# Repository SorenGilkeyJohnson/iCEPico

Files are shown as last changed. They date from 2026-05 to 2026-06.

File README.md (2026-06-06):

# iCEPico

> A compact development board combining the **RP2350** microcontroller and the **ICE40UP5K-SG48I** FPGA in a Raspberry Pi Pico form factor.

---

## Overview

The iCEPico is a custom PCB that pairs the RP2350 with the Lattice ICE40UP5K-SG48I FPGA. The board is modelled after the Raspberry Pi Pico, with the addition of the FPGA and a +1V2 regulator to supply it. The board matches the physical dimensions of the Pico, though it does **not** replicate the Pico's pinout.

I made this project because I wanted to learn FPGA design. Initially, I thought about using a BGA package but decided to go with QFN instead due to PCB costs and complexity. I had previously designed for the RP2040 but never the RP2350. I plan to use the project as a general-purpose dev board, a learning tool for FPGAs for me, and to teach students at my school's robotics club.

---
[Here is KiCanvas!](https://kicanvas.org/?repo=https%3A%2F%2Fgithub.com%2FSorenGilkeyJohnson%2FiCEPico%2Ftree%2Fmain%2FKiCad)

## Board Images

<table>
  <tr>
    <td align="center"><strong>Top View</strong></td>
    <td align="center"><strong>Bottom View</strong></td>
  </tr>
  <tr>
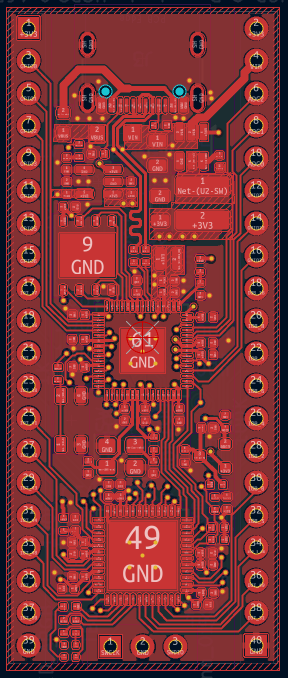
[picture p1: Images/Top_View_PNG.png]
Top View
    <td></td>
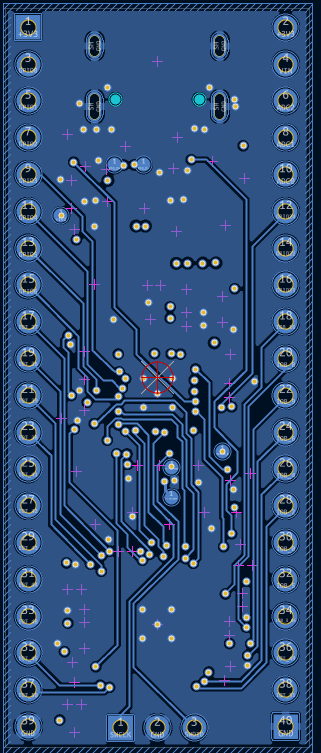
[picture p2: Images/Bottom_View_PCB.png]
Bottom View
    <td></td>
  </tr>
  <tr>
    <td align="center"><strong>3D Top</strong></td>
    <td align="center"><strong>3D Bottom</strong></td>
  </tr>
  <tr>
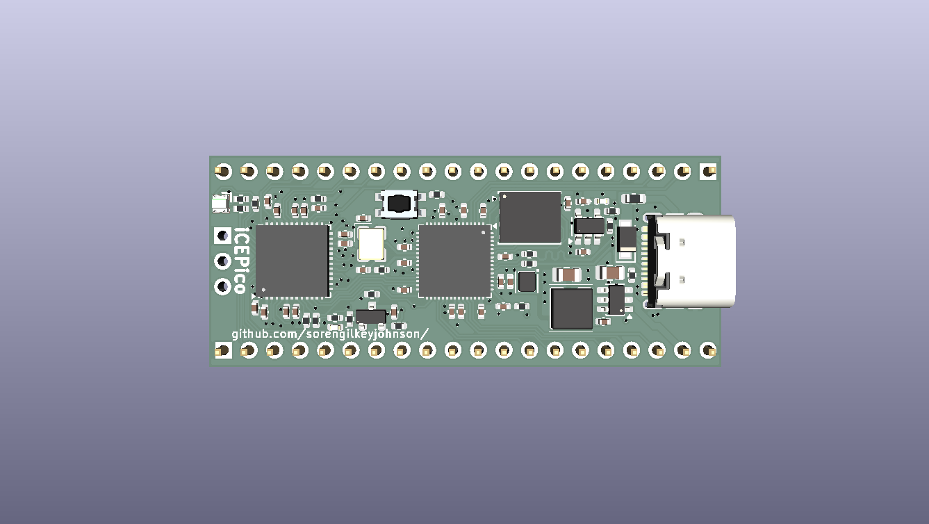
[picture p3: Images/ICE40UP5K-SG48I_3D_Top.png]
3D Top
    <td></td>
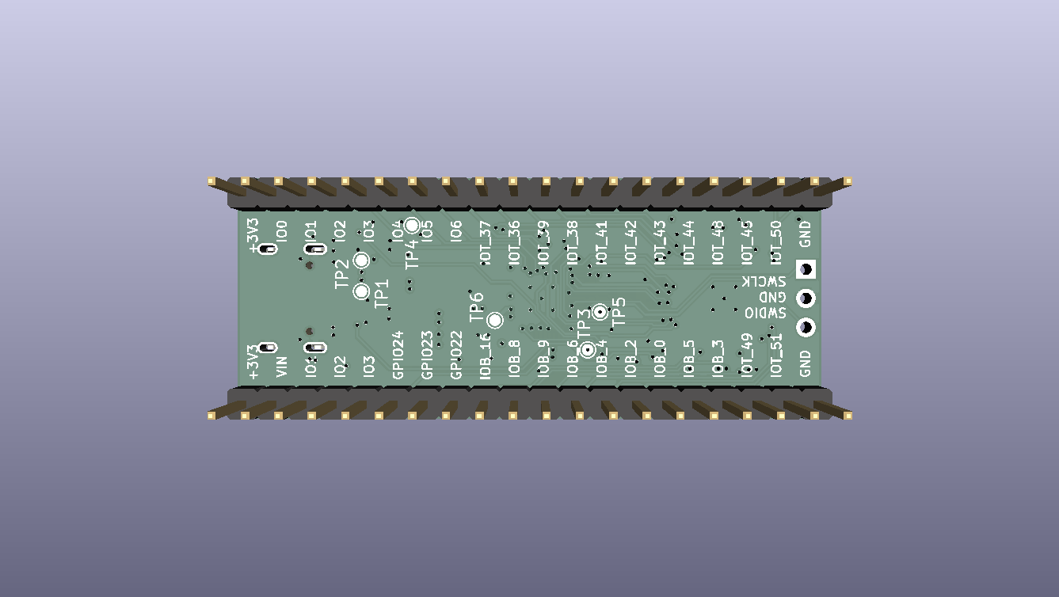
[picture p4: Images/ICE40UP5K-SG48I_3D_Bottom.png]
3D Bottom
    <td></td>
  </tr>
</table>

 [View Schematic (PDF)](Images/ICE40UP5K-SG48I_Schematic.pdf)

---

## Hardware

| Component | Part |
|---|---|
| Microcontroller | RP2350 |
| FPGA | Lattice ICE40UP5K-SG48I |
| QSPI Flash | W25Q128JVP |
| 3.3V Regulator | AP63203 (Buck) |
| 1.2V Regulator | TLV75612PDBV (LDO) |

### RP2350 <-> FPGA Interconnect

The FPGA flash is the RP2350 via bit-banging. The two chips share **8 GPIO lines** aligned to the RP2350's HSTX peripheral.

### PCB Stack-Up

| Layer | Function |
|---|---|
| 1 | Signal / Components |
| 2 | GND |
| 3 | PWR (primarily 3V3) |
| 4 | Signal |

---

## Power

The board can be powered via:
- **USB-C**      : 5V VBUS through a Schottky diode
- **VIN header** : direct voltage input

---

## Programming

| Method | Target | Description |
|---|---|---|
| USB (UF2) | RP2350 | Drag-and-drop bootloader over USB-C |
| SWD | RP2350 | Debug header for OpenOCD / probe-rs |
| Bit-bang (via RP2350) | ICE40 FPGA | FPGA bitstream loaded by the RP2350 firmware |

---

## Pinout

| Pin | Left Signal | | Right Signal | Pin |
|-----|---|---|---|-----|
| 1  | GND | | +3V3 | 2  |
| 3  | GPIO0 | | +VIN | 4  |
| 5  | GPIO1 | | ADC2 | 6  |
| 7  | GPIO2 | | ADC1 | 8  |
| 9  | GPIO3 | | ADC0 | 10 |
| 11 | GPIO4 | | GPIO24 | 12 |
| 13 | GPIO5 | | GPIO23 | 14 |
| 15 | GPIO6 | | GPIO22 | 16 |
| 17 | IOT_37 | | IOB_16 | 18 |
| 19 | IOT_36 | | IOB_8 | 20 |
| 21 | IOT_39 | | IOB_9 | 22 |
| 23 | IOT_38 | | IOB_6 | 24 |
| 25 | IOT_41 | | IOB_4 | 26 |
| 27 | IOT_42 | | IOB_2 | 28 |
| 29 | IOT_43 | | IOB_0 | 30 |
| 31 | IOT_44 | | IOB_5 | 32 |
| 33 | IOT_48 | | IOB_3 | 34 |
| 35 | GND | | GND | 36 |
| 37 | IOT_45 | | IOT_49 | 38 |
| 39 | IOT_50 | | IOT_51 | 40 |

---

## Repository Structure

```
iCEPico/
├── Images/                          # Board renders and schematic export
│   ├── Bottom_View_PCB.png
│   ├── ICE40UP5K-SG48I_3D_Bottom.png
│   ├── ICE40UP5K-SG48I_3D_Top.png
│   ├── ICE40UP5K-SG48I_Schematic.pdf
│   └── Top_View_PNG.png
├── KiCad/                           # KiCad project files
│   ├── ICE40UP5K-SG48I.kicad_pcb
│   ├── ICE40UP5K-SG48I.kicad_prl
│   ├── ICE40UP5K-SG48I.kicad_pro
│   └── ICE40UP5K-SG48I.kicad_sch
├── fabrication/                     # Fabrication outputs
│   ├── bom.csv
│   ├── gerbers.zip
│   └── pick_and_place.csv
├── hardware/                        # Hardware source files
│   ├── ICE40UP5K-SG48I.kicad_pcb
│   ├── ICE40UP5K-SG48I.kicad_pro
│   └── ICE40UP5K-SG48I.kicad_sch
├── LICENSE
└── README.md
```

---

## License

See [LICENSE](LICENSE) for details.

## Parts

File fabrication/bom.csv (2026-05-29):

Index | LCSC# | MPN | Manufacturer | Package | Customer # | Description | RoHS | Quantity | MOQ | Multiple | Unit Price($) | Extended Price($) | Product Link
1 | C52895 | BSS138 | onsemi | SOT-23 |  | N-Channel 50V 0.22A 0.36W Surface Mount SOT-23 | yes | 10 | 10 | 10 | 0.0680 | 0.68 | https://www.lcsc.com/product-detail/C52895.html
2 | C20625731 | ABM8-272-T3 | ABRACON | SMD3225-4P |  | ±30ppm 10pF ±30ppm SMD3225-4P Crystals RoHS | yes | 5 | 5 | 5 | 0.2947 | 1.47 | https://www.lcsc.com/product-detail/C20625731.html
3 | C42411118 | RP2350A | Raspberry Pi | QFN-60-EP(7x7) |  | QFN-60-EP(7x7) Microcontrollers RoHS | yes | 1 | 1 | 1 | 1.1886 | 3.57 | https://www.lcsc.com/product-detail/C42411118.html
4 | C2441427 | W25Q128JVPIM TR | Winbond | WSON-8-EP(5x6) |  | FLASH - NOR Memory IC 128Mbit SPI 133MHz WSON-8-EP(5x6) | yes | 1 | 1 | 1 | 3.0644 | 9.19 | https://www.lcsc.com/product-detail/C2441427.html
5 | C2877864 | TLV75512PDBVR | TI | SOT-23-5 |  | Linear Voltage Regulator IC Positive Fixed 1 Output 500mA SOT-23-5 | yes | 5 | 5 | 5 | 0.1722 | 0.86 | https://www.lcsc.com/product-detail/C2877864.html
6 | C780769 | AP63203WU-7 | DIODES | TSOT-23-6 |  | 1.1MHz Step-down type Fixed 2A 3.3V 3.8V~32V TSOT-23-6 Voltage Regulators - DC DC Switching Regulators RoHS | yes | 3 | 1 | 1 | 0.5463 | 1.64 | https://www.lcsc.com/product-detail/C780769.html
7 | C2678152 | ICE40UP5K-SG48I | Lattice | QFN-48-EP(7x7) |  | 5280 660 QFN-48-EP(7x7) FPGAs (Field Programmable Gate Array) RoHS | yes | 1 | 1 | 1 | 8.0688 | 24.21 | https://www.lcsc.com/product-detail/C2678152.html
8 | C138002 | RC0402FR-0733RL | YAGEO | 0402 |  | 62.5mW 33Ω 50V Thick Film Resistor ±100ppm/℃ ±1% 0402 Chip Resistor - Surface Mount RoHS | yes | 100 | 100 | 100 | 0.0009 | 0.09 | https://www.lcsc.com/product-detail/C138002.html
9 | C2909343 | FRC0402F27R0TS | FOJAN | 0402 |  | 27Ω ±1% 62.5mW 0402 Thick Film Resistor | yes | 100 | 100 | 100 | 0.0007 | 0.07 | https://www.lcsc.com/product-detail/C2909343.html
10 | C106235 | RC0402FR-071KL | YAGEO | 0402 |  | 1kΩ 62.5mW 50V Thick Film Resistor ±100ppm/℃ ±1% 0402 Chip Resistor - Surface Mount RoHS | yes | 100 | 100 | 100 | 0.0009 | 0.09 | https://www.lcsc.com/product-detail/C106235.html
11 | C60491 | RC0402FR-07100KL | YAGEO | 0402 |  | 100kΩ 62.5mW 50V Thick Film Resistor ±100ppm/℃ ±1% 0402 Chip Resistor - Surface Mount RoHS | yes | 100 | 100 | 100 | 0.0009 | 0.09 | https://www.lcsc.com/product-detail/C60491.html
12 | C60490 | RC0402FR-0710KL | YAGEO | 0402 |  | 62.5mW 10kΩ 50V Thick Film Resistor ±100ppm/℃ ±1% 0402 Chip Resistor - Surface Mount RoHS | yes | 100 | 100 | 100 | 0.0009 | 0.09 | https://www.lcsc.com/product-detail/C60490.html
13 | C106232 | RC0402FR-07100RL | YAGEO | 0402 |  | 100Ω 62.5mW 50V Thick Film Resistor ±100ppm/℃ ±1% 0402 Chip Resistor - Surface Mount RoHS | yes | 100 | 100 | 100 | 0.0008 | 0.08 | https://www.lcsc.com/product-detail/C106232.html
14 | C105872 | RC0402FR-075K1L | YAGEO | 0402 |  | 5.1kΩ 62.5mW 50V Thick Film Resistor ±100ppm/℃ ±1% 0402 Chip Resistor - Surface Mount RoHS | yes | 100 | 100 | 100 | 0.0009 | 0.09 | https://www.lcsc.com/product-detail/C105872.html
15 | C131394 | CC0402KRX7R9BB104 | YAGEO | 0402 |  | 100nF ±10% 50V Ceramic Capacitor X7R 0402 | yes | 100 | 100 | 100 | 0.0037 | 0.37 | https://www.lcsc.com/product-detail/C131394.html
16 | C42411119 | AOTA-B201610S3R3-101-T | ABRACON | 0806 |  | 2.1A 3.3uH 115mΩ 2.4A Molded Inductor 0806 Fixed Inductors RoHS | yes | 5 | 5 | 5 | 0.2843 | 1.42 | https://www.lcsc.com/product-detail/C42411119.html
17 | C6808101 | ANR4030T3R9M | APV | SMD,4x4mm |  | 2.3A 3.9uH ±20% 3.3A Magnetic Shielded Inductor SMD,4x4mm Fixed Inductors RoHS | yes | 10 | 10 | 10 | 0.0418 | 0.42 | https://www.lcsc.com/product-detail/C6808101.html
18 | C2765186 | TYPE-C 16PIN 2MD(073) | SHOU HAN | SMD |  | USB-C (USB TYPE-C) Receptacle Connector 16 Position Surface Mount, Right Angle | yes | 20 | 20 | 20 | 0.0740 | 1.48 | https://www.lcsc.com/product-detail/C2765186.html
19 | C41380229 | BSMD0603C-1200T | BHFUSE | 0603 |  | 2A Fuse Surface Mount 0603 | yes | 10 | 10 | 10 | 0.0419 | 0.42 | https://www.lcsc.com/product-detail/C41380229.html
20 | C20608784 | YLED0402G | YONGYUTAI | 0402 |  | Emerald Green 525nm LED Indication - Discrete 2.4V~3.1V 0402 | yes | 50 | 50 | 50 | 0.0133 | 0.67 | https://www.lcsc.com/product-detail/C20608784.html
21 | C965840 | XL-1615RGBC-RF | XINGLIGHT | SMD-4P,1.6x1.5mm |  | 120° SMD-4P,1.6x1.5mm LED Indication - Discrete RoHS | yes | 50 | 50 | 50 | 0.0194 | 0.97 | https://www.lcsc.com/product-detail/C965840.html
22 | C179430 | PMEG4010ER,115 | Nexperia | SOD-123W |  | Diode 40V 1A Surface Mount SOD-123W | yes | 5 | 5 | 5 | 0.2910 | 1.46 | https://www.lcsc.com/product-detail/C179430.html
23 | C106997 | CC0402JRNPO9BN150 | YAGEO | 0402 |  | 15pF ±5% 50V Ceramic Capacitor NP0 0402 | yes | 100 | 100 | 100 | 0.0013 | 0.13 | https://www.lcsc.com/product-detail/C106997.html
24 | C602037 | CL21A226MAYNNNE | Samsung Electro-Mechanics | 0805 |  | 22uF ±20% 25V Ceramic Capacitor X5R 0805 | yes | 10 | 10 | 10 | 0.0546 | 0.55 | https://www.lcsc.com/product-detail/C602037.html
25 | C14442 | CL05B102KB5NNNC | Samsung Electro-Mechanics | 0402 |  | 1nF ±10% 50V Ceramic Capacitor X7R 0402 | yes | 100 | 100 | 100 | 0.0018 | 0.18 | https://www.lcsc.com/product-detail/C14442.html
26 | C29266 | CL05A105KO5NNNC | Samsung Electro-Mechanics | 0402 |  | 1uF ±10% 16V Ceramic Capacitor X5R 0402 | yes | 100 | 100 | 100 | 0.0035 | 0.35 | https://www.lcsc.com/product-detail/C29266.html
27 | C440198 | GRM21BR61H106KE43L | muRata | 0805 |  | 10uF ±10% 50V Ceramic Capacitor X5R 0805 | yes | 10 | 10 | 10 | 0.0981 | 0.98 | https://www.lcsc.com/product-detail/C440198.html
28 | C318563 | CL05A475MO5NUNC | Samsung Electro-Mechanics | 0402 |  | 4.7uF ±20% 16V Ceramic Capacitor X5R 0402 | yes | 40 | 20 | 20 | 0.0105 | 0.42 | https://www.lcsc.com/product-detail/C318563.html

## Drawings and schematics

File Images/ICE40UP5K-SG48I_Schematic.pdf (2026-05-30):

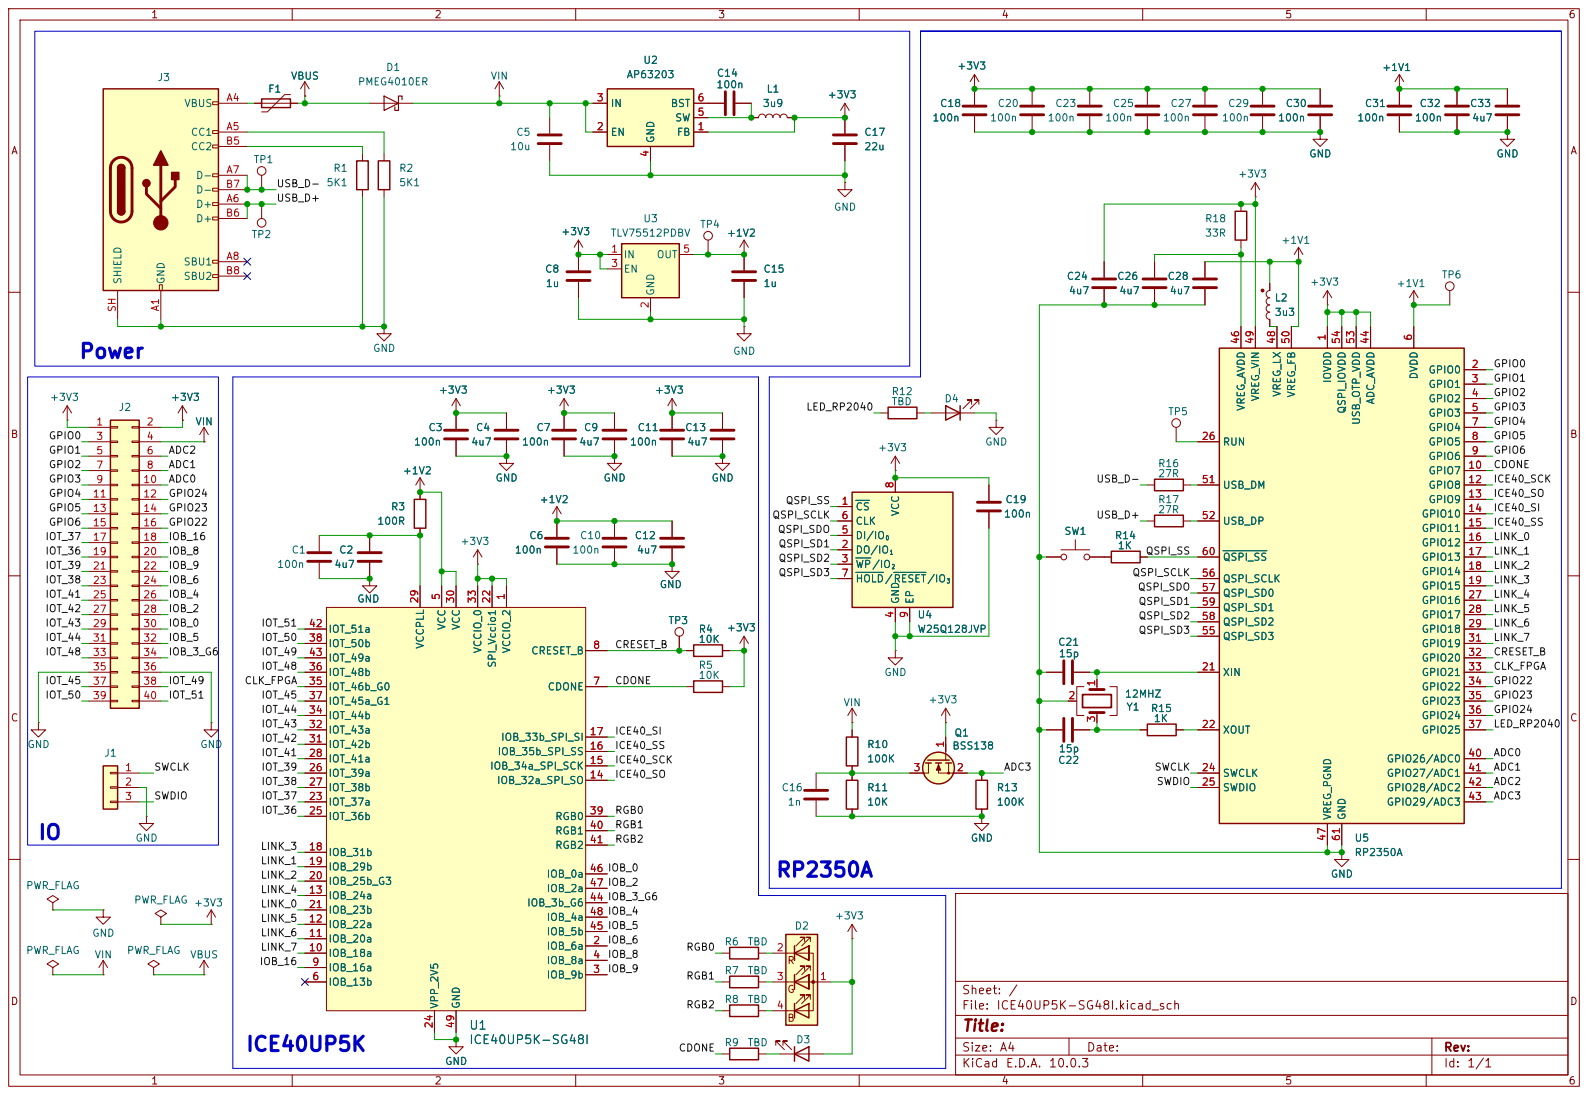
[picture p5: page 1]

4 DI/IO0 5 CLK 6 HOLD/RESET/IO3 7 VCC
ICE40UP5K-SG48I VCCIO_2

Size: A4 | Rev:
KiCad E.D.A. 10.0.3 | Id: 1/1

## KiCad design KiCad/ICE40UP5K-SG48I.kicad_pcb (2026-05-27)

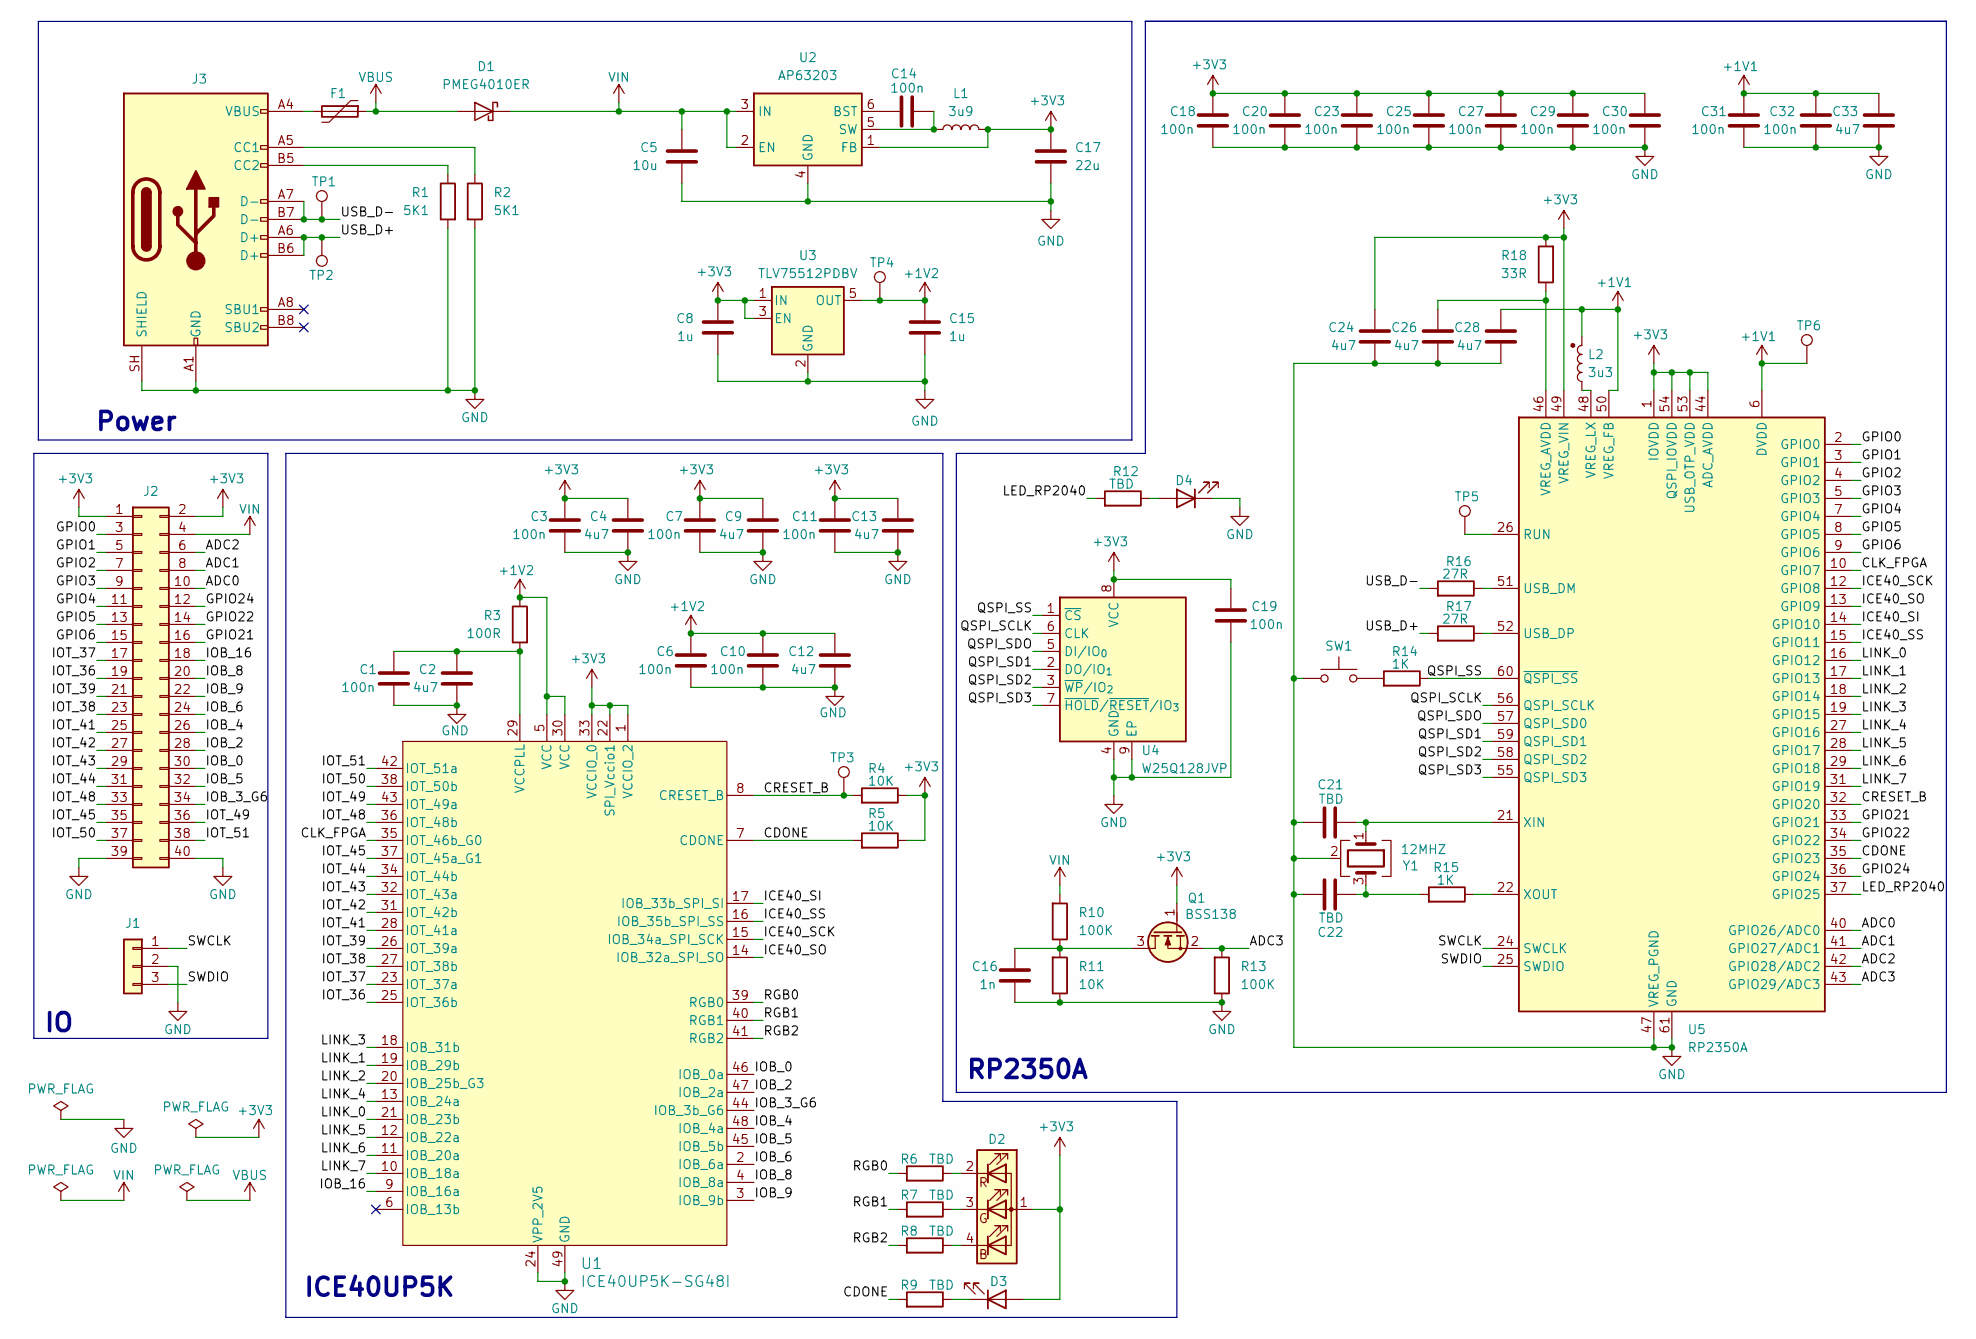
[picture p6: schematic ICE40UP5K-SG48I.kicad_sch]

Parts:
C1, C3, C6, C7, C10, C11, C14, C18, C19, C20, C23, C25, C27, C29, C30, C31, C32: 100n; C_0402_1005Metric
C2, C4, C9, C12, C13, C24, C26, C28, C33: 4u7; C_0402_1005Metric
C5: 10u; C_0805_2012Metric
C8, C15: 1u; C_0402_1005Metric
C16: 1n; C_0402_1005Metric
C17: 22u; C_0805_2012Metric
C21, C22: TBD; C_0402_1005Metric
D1: PMEG4010ER; Nexperia_CFP3_SOD-123W
D2: LED_ARGB; LED_SK6812_EC15_1.5x1.5mm
D3, D4: LED; LED_0402_1005Metric
F1: Polyfuse; Fuse_0603_1608Metric
J1: Conn_01x03; PinHeader_1x03_P2.54mm_Vertical
J2: Conn_02x20_Odd_Even; PinHeader_2x20_P2.54mm_Vertical
J3: USB_C_Receptacle_USB2.0_16P; USB_C_Receptacle_GCT_USB4105-xx-A_16P_TopMnt_Horizontal
L1: 3u9; L_Chilisin_BWVS00404012
L2: 3u3; L_Changjiang_FTC201607S
Q1: BSS138; SOT-23
R1, R2: 5K1; R_0402_1005Metric
R3: 100R; R_0402_1005Metric
R4, R5, R11: 10K; R_0402_1005Metric
R6, R7, R8, R9, R12: TBD; R_0402_1005Metric
R10, R13: 100K; R_0402_1005Metric
R14, R15: 1K; R_0402_1005Metric
R16, R17: 27R; R_0402_1005Metric
R18: 33R; R_0402_1005Metric
SW1: SW_MEC_5G; SW_3_42 4-PIN Button
TP1, TP2, TP3, TP4, TP5, TP6: TestPoint; TestPoint_Pad_D1.0mm
U1: ICE40UP5K-SG48I; QFN-48-1EP_7x7mm_P0.5mm_EP5.3x5.3mm
U2: AP63203; TSOT-23-6
U3: TLV75512PDBV; SOT-23-5
U4: W25Q128JVP; WSON-8-1EP_6x5mm_P1.27mm_EP3.4x4.3mm
U5: RP2350A; QFN-60-1EP_7x7mm_P0.4mm_EP3.4x3.4mm
Y1: 12MHZ; Crystal_SMD_3225-4Pin_3.2x2.5mm

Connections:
+1V1: C28.1, C31.1, C32.1, C33.1, L2.1, TP6.1 (1_1), U5.6 (DVDD), U5.23 (DVDD), U5.39 (DVDD), U5.50 (VREG_FB)
+1V2: C6.1, C10.1, C12.1, C15.1, R3.1, TP4.1 (1_1), U1.5 (VCC), U1.30 (VCC), U3.5 (OUT)
+3V3: C3.1, C4.1, C7.1, C8.1, C9.1, C11.1, C13.1, C17.1, C18.1, C19.1, C20.1, C23.1, C24.1, C25.1, C27.1, C29.1, C30.1, D2.1 (A), D3.2 (A), J2.1, J2.2, L1.2, Q1.1 (G), R4.1, R5.1, R18.1, U1.1 (VCCIO_2), U1.22 (SPI_Vccio1), U1.33 (VCCIO_0), U2.1 (FB), U3.1 (IN), U3.3 (EN), U4.8 (VCC), U5.1 (IOVDD), U5.11 (IOVDD), U5.20 (IOVDD), U5.30 (IOVDD), U5.38 (IOVDD), U5.44 (ADC_AVDD), U5.45 (IOVDD), U5.49 (VREG_VIN), U5.53 (USB_OTP_VDD), U5.54 (QSPI_IOVDD)
/ADC0: J2.10, U5.40 (GPIO26/ADC0)
/ADC1: J2.8, U5.41 (GPIO27/ADC1)
/ADC2: J2.6, U5.42 (GPIO28/ADC2)
/ADC3: Q1.2 (S), R13.1, U5.43 (GPIO29/ADC3)
/CDONE: R5.2, R9.2, U1.7 (CDONE), U5.35 (GPIO23)
/CLK_FPGA: U1.35 (IOT_46b_G0), U5.10 (GPIO7)
/CRESET_B: R4.2, TP3.1 (1_1), U1.8 (CRESET_B), U5.32 (GPIO20)
/GPIO0: J2.3, U5.2 (GPIO0)
/GPIO1: J2.5, U5.3 (GPIO1)
/GPIO2: J2.7, U5.4 (GPIO2)
/GPIO3: J2.9, U5.5 (GPIO3)
/GPIO4: J2.11, U5.7 (GPIO4)
/GPIO5: J2.13, U5.8 (GPIO5)
/GPIO6: J2.15, U5.9 (GPIO6)
/GPIO21: J2.16, U5.33 (GPIO21)
/GPIO22: J2.14, U5.34 (GPIO22)
/GPIO24: J2.12, U5.36 (GPIO24)
/ICE40_SCK: U1.15 (IOB_34a_SPI_SCK), U5.12 (GPIO8)
/ICE40_SI: U1.17 (IOB_33b_SPI_SI), U5.14 (GPIO10)
/ICE40_SO: U1.14 (IOB_32a_SPI_SO), U5.13 (GPIO9)
/ICE40_SS: U1.16 (IOB_35b_SPI_SS), U5.15 (GPIO11)
/IOB_0: J2.30, U1.46 (IOB_0a)
/IOB_2: J2.28, U1.47 (IOB_2a)
/IOB_3_G6: J2.34, U1.44 (IOB_3b_G6)
/IOB_4: J2.26, U1.48 (IOB_4a)
/IOB_5: J2.32, U1.45 (IOB_5b)
/IOB_6: J2.24, U1.2 (IOB_6a)
/IOB_8: J2.20, U1.4 (IOB_8a)
/IOB_9: J2.22, U1.3 (IOB_9b)
/IOB_16: J2.18, U1.9 (IOB_16a)
/IOT_36: J2.19, U1.25 (IOT_36b)
/IOT_37: J2.17, U1.23 (IOT_37a)
/IOT_38: J2.23, U1.27 (IOT_38b)
/IOT_39: J2.21, U1.26 (IOT_39a)
/IOT_41: J2.25, U1.28 (IOT_41a)
/IOT_42: J2.27, U1.31 (IOT_42b)
/IOT_43: J2.29, U1.32 (IOT_43a)
/IOT_44: J2.31, U1.34 (IOT_44b)
/IOT_45: J2.35, U1.37 (IOT_45a_G1)
/IOT_48: J2.33, U1.36 (IOT_48b)
/IOT_49: J2.36, U1.43 (IOT_49a)
/IOT_50: J2.37, U1.38 (IOT_50b)
/IOT_51: J2.38, U1.42 (IOT_51a)
/LED_RP2040: R12.2, U5.37 (GPIO25)
/LINK_0: U1.21 (IOB_23b), U5.16 (GPIO12)
/LINK_1: U1.19 (IOB_29b), U5.17 (GPIO13)
/LINK_2: U1.20 (IOB_25b_G3), U5.18 (GPIO14)
/LINK_3: U1.18 (IOB_31b), U5.19 (GPIO15)
/LINK_4: U1.13 (IOB_24a), U5.27 (GPIO16)
/LINK_5: U1.12 (IOB_22a), U5.28 (GPIO17)
/LINK_6: U1.11 (IOB_20a), U5.29 (GPIO18)
/LINK_7: U1.10 (IOB_18a), U5.31 (GPIO19)
/QSPI_SCLK: U4.6 (CLK), U5.56 (QSPI_SCLK)
/QSPI_SD1: U4.2 (DO/IO_{1}), U5.59 (QSPI_SD1)
/QSPI_SD2: U4.3 (~WP/IO_{2}), U5.58 (QSPI_SD2)
/QSPI_SD3: U4.7 (~HOLD/~RESET/IO_{3}), U5.55 (QSPI_SD3)
/QSPI_SDO: U4.5 (DI/IO_{0}), U5.57 (QSPI_SD0)
/QSPI_SS: R14.1, U4.1 (~CS), U5.60 (~QSPI_SS)
/RGB0: R6.2, U1.39 (RGB0)
/RGB1: R7.2, U1.40 (RGB1)
/RGB2: R8.2, U1.41 (RGB2)
/SWCLK: J1.1, U5.24 (SWCLK)
/SWDIO: J1.3, U5.25 (SWDIO)
/USB_D+: J3.A6 (D+), J3.B6 (D+), R17.2, TP2.1 (1_1)
/USB_D-: J3.A7 (D-), J3.B7 (D-), R16.2, TP1.1 (1_1)
GND: C1.2, C2.2, C3.2, C4.2, C5.2, C6.2, C7.2, C8.2, C9.2, C10.2, C11.2, C12.2, C13.2, C15.2, C16.2, C17.2, C18.2, C19.2, C20.2, C21.1, C22.1, C23.2, C24.2, C25.2, C26.2, C27.2, C28.2, C29.2, C30.2, C31.2, C32.2, C33.2, D4.1 (K), J1.2, J2.39, J2.40, J3.A1 (GND), J3.A12 (GND), J3.B1 (GND), J3.B12 (GND), J3.SH (SHIELD), R1.2, R2.2, R11.2, R13.2, SW1.3, SW1.4 (B), U1.24 (VPP_2V5), U1.49 (GND), U2.4 (GND), U3.2 (GND), U3.4 (NC), U4.4 (GND), U4.9 (EP), U5.47 (VREG_PGND), U5.61 (GND), Y1.2 (G), Y1.4 (G)
unnamed: C22.2, R15.2, Y1.3
unnamed: D2.4 (BK), R8.1
unnamed: D2.3 (GK), R7.1
unnamed: D2.2 (RK), R6.1
unnamed: D3.1 (K), R9.1
unnamed: D4.2 (A), R12.1
unnamed: F1.2, J3.A4 (VBUS), J3.A9 (VBUS), J3.B4 (VBUS), J3.B9 (VBUS)
unnamed: J3.A5 (CC1), R2.1
unnamed: J3.B5 (CC2), R1.1
unnamed: C16.1, Q1.3 (D), R10.2, R11.1
unnamed: R14.2, SW1.1, SW1.2 (A)
unnamed: C1.1, C2.1, R3.2, U1.29 (VCCPLL)
unnamed: C14.1, U2.6 (BST)
unnamed: C14.2, L1.1, U2.5 (SW)
unnamed: TP5.1 (1_1), U5.26 (RUN)
unnamed: R16.1, U5.51 (USB_DM)
unnamed: R17.1, U5.52 (USB_DP)
unnamed: C26.1, R18.2, U5.46 (VREG_AVDD)
unnamed: L2.2, U5.48 (VREG_LX)
unnamed: C21.2, U5.21 (XIN), Y1.1
unnamed: R15.1, U5.22 (XOUT)
VBUS: D1.2 (A), F1.1
VIN: C5.1, D1.1 (K), J2.4, R10.1, U2.2 (EN), U2.3 (IN)

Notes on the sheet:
Power
RP2350A
ICE40UP5K

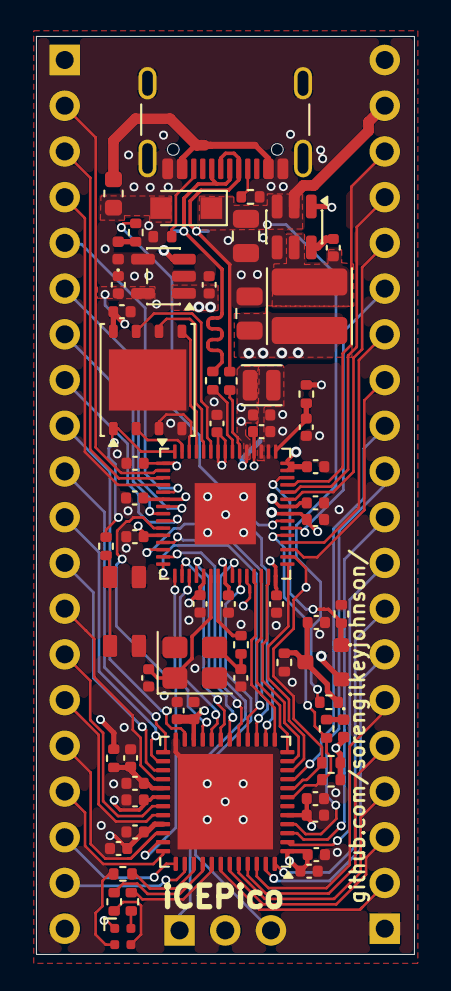
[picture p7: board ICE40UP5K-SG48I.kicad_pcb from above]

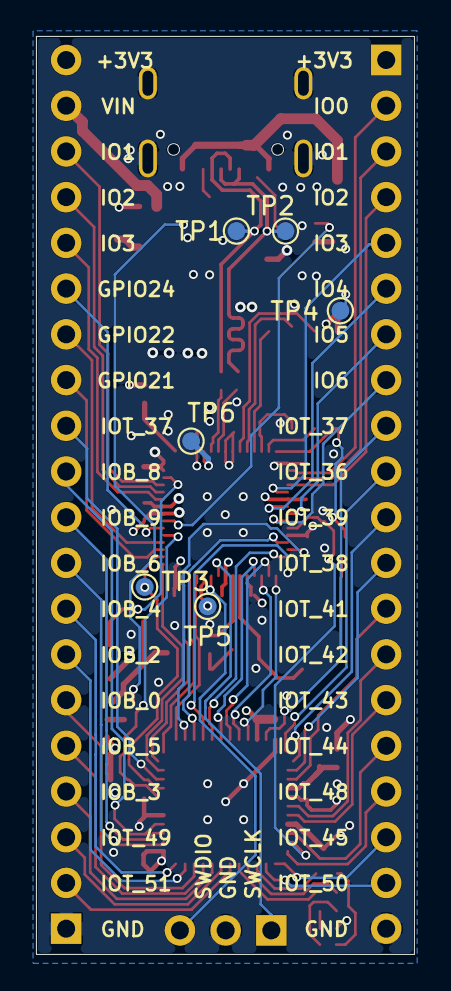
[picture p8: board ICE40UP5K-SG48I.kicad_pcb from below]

Board: 4 copper layers, 21.0 x 51.0 mm, 75 parts (6 on the bottom side), 92 nets.

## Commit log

2026-05-29 Add bom.csv to the project
    [bom.csv]
2026-05-29 Add pick_and_place.csv to fabrication directory
    [pick_and_place.csv]
2026-05-29 Add KiCad project file for ICE40UP5K-SG48I
2026-05-29 Enhance README with detailed board information
    Expanded the README to provide detailed information about the iCEPico development board, including hardware specifications, power options, programming methods, pinout, and repository structure.
